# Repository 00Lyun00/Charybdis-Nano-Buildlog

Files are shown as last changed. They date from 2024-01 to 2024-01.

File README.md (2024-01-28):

# Charybdis Nano Buildlog
This is my rendition of the Charybdis Nano split keyboard made by [BastardKB.](https://github.com/bastardkb/charybdis)  
  
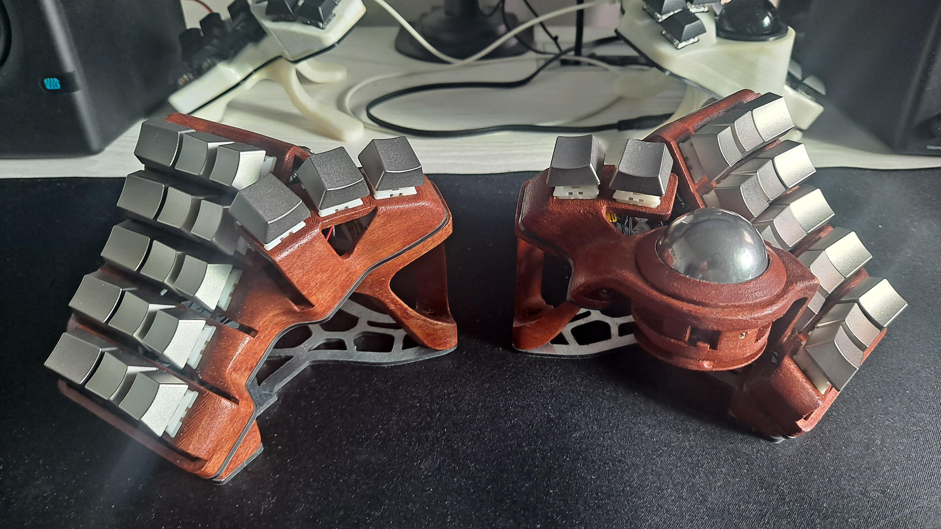
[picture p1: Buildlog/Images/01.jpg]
  
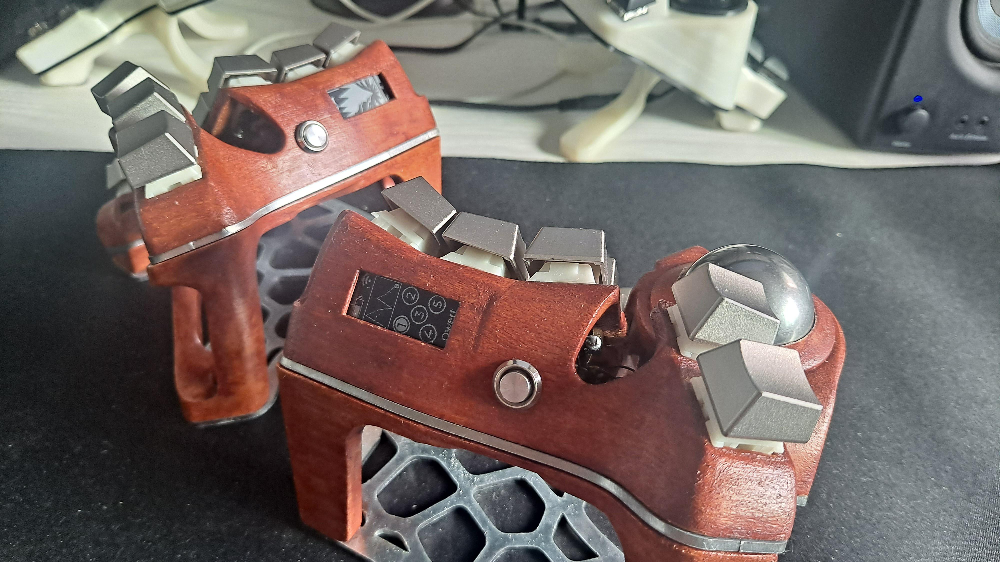
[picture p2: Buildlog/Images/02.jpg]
  
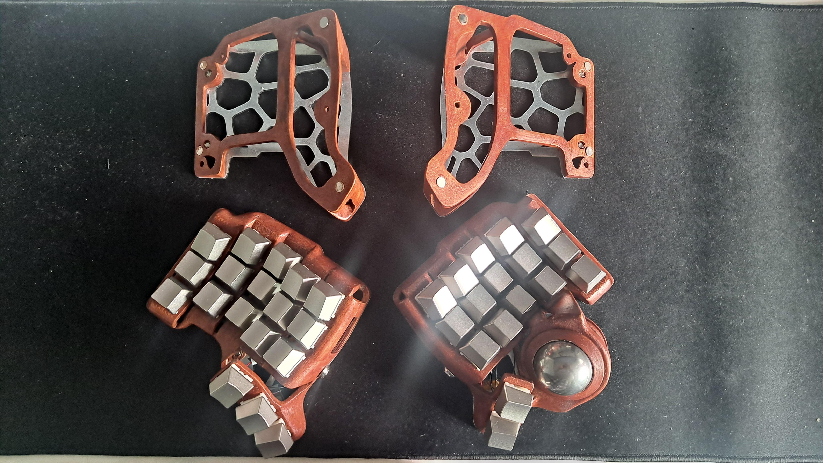
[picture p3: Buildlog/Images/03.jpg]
  
  
Intended to be a wireless-only build, I removed the TRRS jack on both cases, added walls to support a nice!view, and made holes to fit a metal on/off switch.  
I used the trackball cover mod to prevent the stainless steel ball from dropping out when I take it off the tent or MagSafe adapter.    
The alien tents have magnets imbedded, making it easier to attach and detach the keyboards.  
With 110mah batteries, I can use the fully charged keyboard for about 5 days before recharging.  
You can see a detailed buildlog in the Buildlog folder.  

## Materials
- Case: CooBean Wood PLA Filament, sanded, stained with generic mahogani wood stain and varnish
- Switches: Gazzew Boba U4
- Keycaps: Ogre Zinc Alloy OEM Keycaps (Korean Local Seller)
- Plates: Laserboost 2mm Galvanized Steel Plates
- Chair Attachment: Ulanzi R094 Magic Arm & Clamp + MagSafe Adapters
  
## Electronics    
- MCU: nice!nano 2.0
- Trackball Sensor: [ufan's original PMW3610 breakboard](https://github.com/ufan/pmw3610_breakout)
- Display: nice!view  
- ZMK Config: [My customized fork from EIGAtech's Config](https://github.com/00Lyun00/zmk-config-charybdis/tree/charybdis3.5)

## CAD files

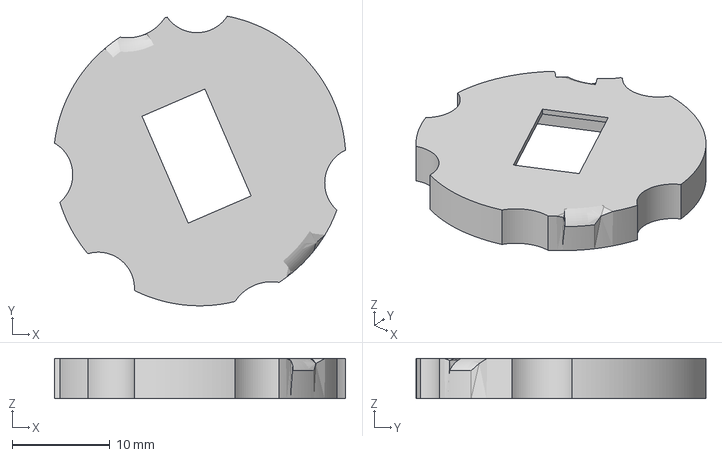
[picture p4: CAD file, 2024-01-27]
Buildlog/Files/PMW3610Adapter v2.3mf
29.7 x 29.6 x 4.10 mm

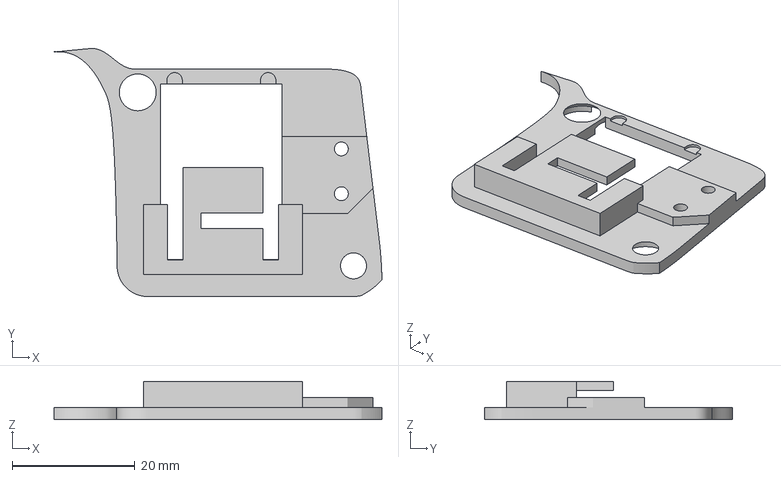
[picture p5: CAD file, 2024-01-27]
Buildlog/Files/MCUHolderRight.3mf
53.4 x 40.4 x 6.22 mm

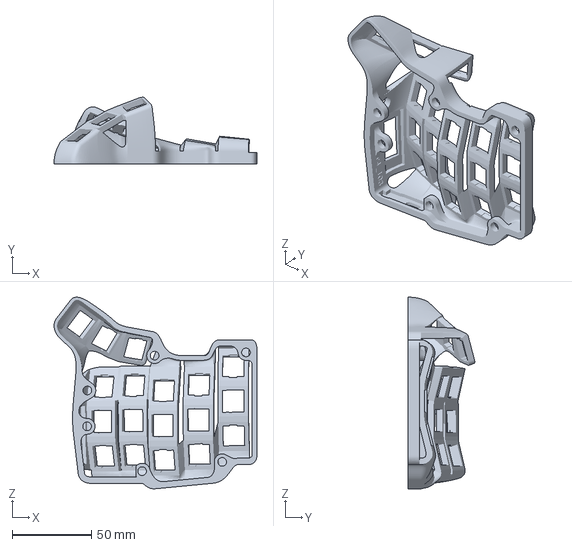
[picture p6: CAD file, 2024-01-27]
Buildlog/Files/WirelessSkeletyl.3mf
128.0 x 42.0 x 120.9 mm

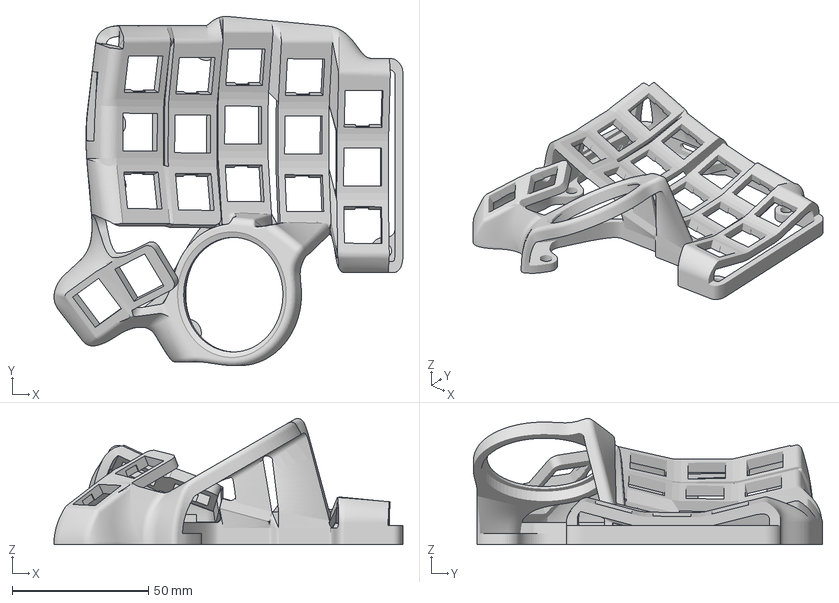
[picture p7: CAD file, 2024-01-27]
Buildlog/Files/WirelessCharybdisNano.3mf
128.0 x 128.1 x 46.2 mm

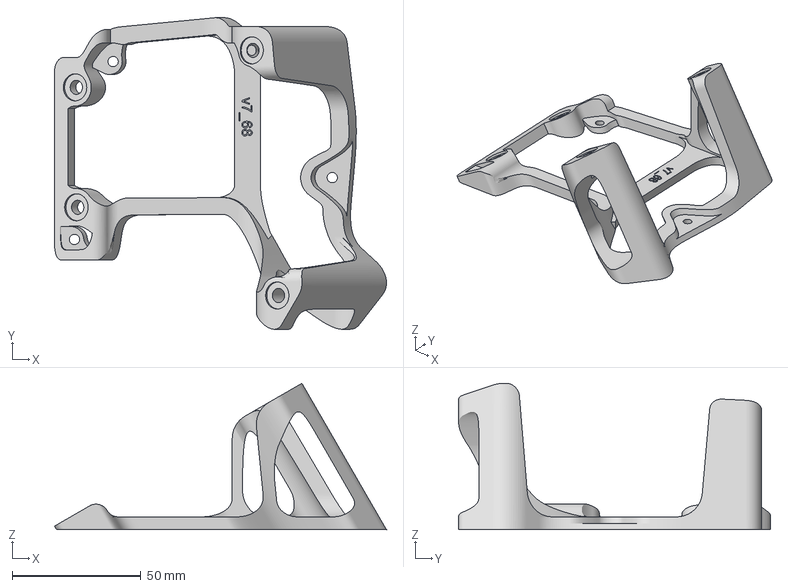
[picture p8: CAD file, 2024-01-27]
Buildlog/Files/AlienTentMagnet.3mf
128.8 x 120.9 x 56.8 mm

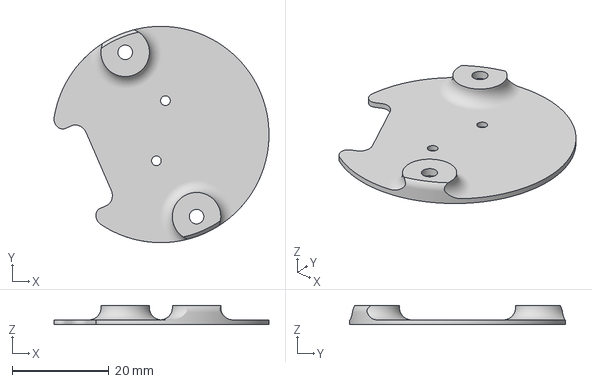
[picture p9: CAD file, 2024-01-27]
Buildlog/Files/PMW3610BottomPlate.3mf
44.4 x 44.7 x 4.00 mm

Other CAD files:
Buildlog/Files/MCUHolderLeft.3mf

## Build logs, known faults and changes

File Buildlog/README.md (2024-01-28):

This buildlog assumes the reader has prior experience in handwiring a keyboard and will skip that part. It is intended to help people with less experience in ZMK, as that was my case.  
   
## Planning
After being inspired to build this keyboard, the first goal I wanted to achieve was using capacitive touch to automatically switch to mouse layer.  
I knew this was possible as I saw username ufan mock up a test build with a stainless steel ball bearing in the ZMK Discord server, so I naturally decided to use one as well.  
With the constraint of having a stainless steel trackball, I thought wood and metal would create an intriguing vintage-furniture-like design.  
Although I learned that I didn't really need an auto-switch mouse layer and thus decided not to use capacitive touch later in the building process, I liked the design theme and decided to keep it.  
  
Regarding functionality, I wanted to make it wireless, add a button switch to save battery, add magnets to the original tents to attach/detach them conveniently, and install nice!view displays to know the pairing status and battery level.  
I knew the first three goals were achievable, but I've never seen someone using both a trackball and display on the same keyboard as pointing devices are currently experimental on ZMK.  
With these challenges in mind, I proceeded to the building process.  
  
I highly recommend watching [EIGAtech's wireless Charybdis video,](https://www.youtube.com/watch?v=Mks7QDxFreY&t) as it was incredibly helpful for me to visualize my build plan.

## Modeling
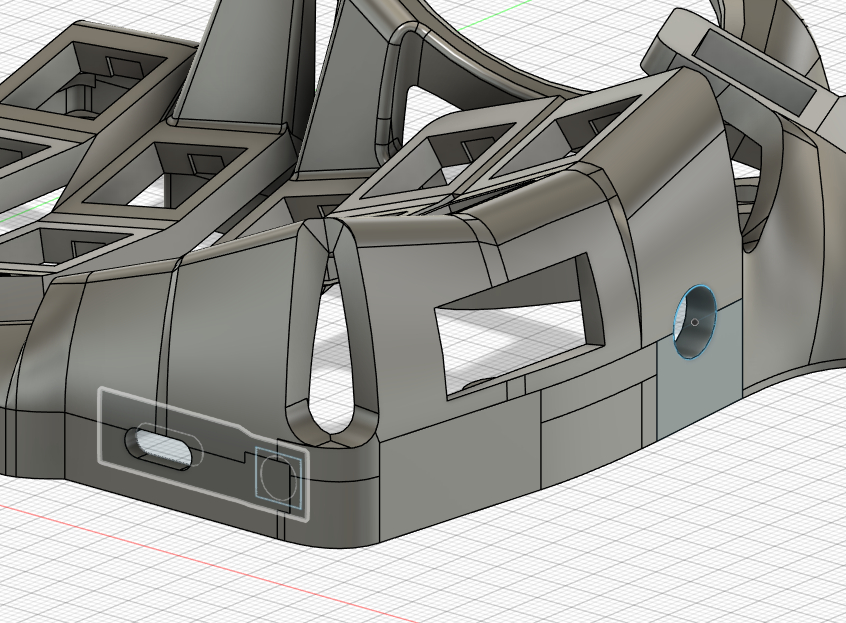
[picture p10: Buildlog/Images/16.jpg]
Three-quarter view of modified case
  
I have practically no knowledge in Fusion360, but as the changes I was about to make were minimal, it fortunately didn't deter the process too much.  
Firstly, I just simply added a hole on the side for the button switch and covered up the TRRS hole.  
I also changed the MCU holder for handwiring so that it didn't hold the TRRS conenector, grabbed on millmax hotswap sockets, and used a 3x6 button switch since that's what I had in stock.    
Everything except for the nice!view part was easy, as there was nothing to hold the nice!view to begin with.  
So I followed [BastardKB's keyboard design video](https://youtu.be/scoX8NZv4MI?si=uietOpE2jdQoaGku&t=1031) to make some walls on the side the exact way he did, and then I made a rectangular hole big enough to fit the nice!view flush.  
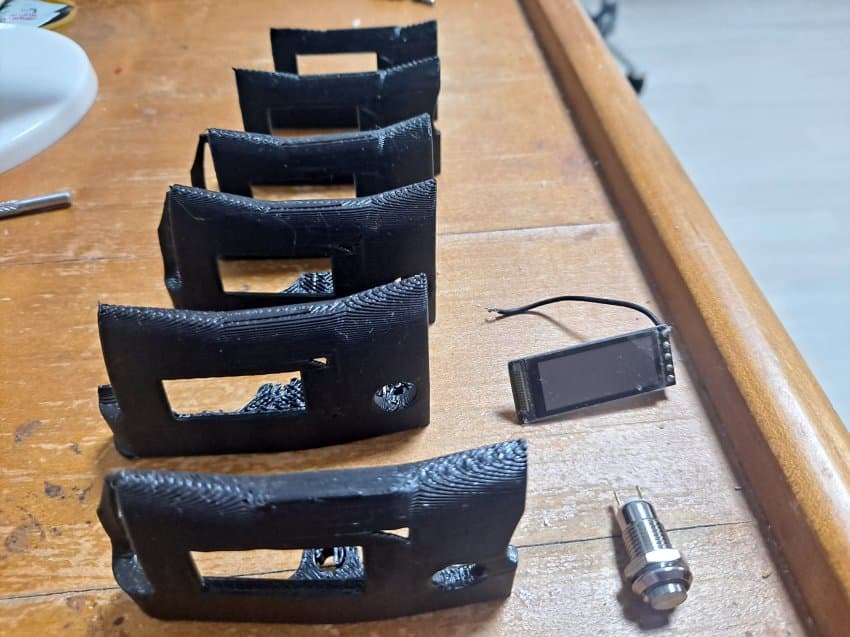
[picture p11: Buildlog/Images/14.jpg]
Multiple nice!view hole variations that show my inexpertise
  
If I was better in using Fusion360, I would have added a latch or any other mechanism to hold the nice!view in place.  
However, as I was limited by the fact that I don't know what I am doing, I simply stopped and decided to glue it in place.  
  
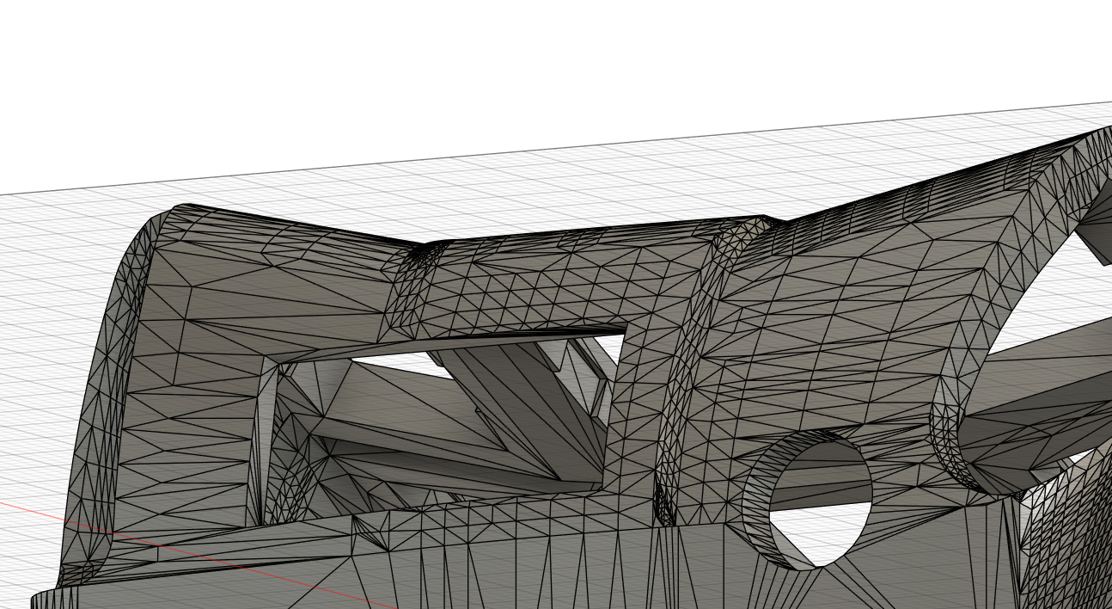
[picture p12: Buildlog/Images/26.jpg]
Flaw of Skeletyl file
  
  
The wall on the Skeletyl file is flawed because it sticks out a bit.  
I lacked the ability to fix this, so I just sanded it down after printing it until that bump disappeared.  
  
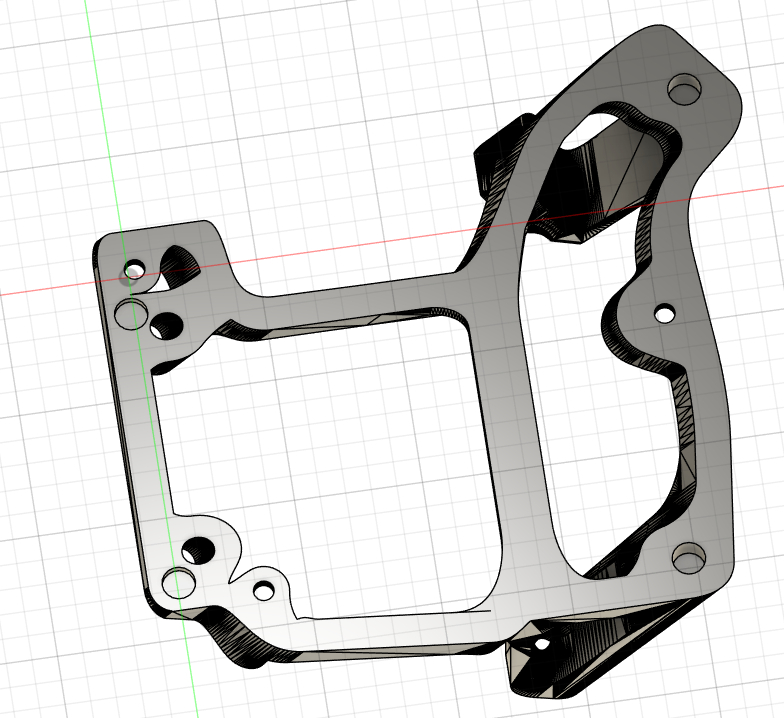
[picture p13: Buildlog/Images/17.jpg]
Alien tent modeling file
  
I also added four holes to the alien tent to hold 6cm magnets.  
The front legs were tall enough to fit two 3x6 magnets, and the back legs only managed to fit one 2x6 magnet each.  
I had to use the magnets this way in order to support the heavy keyboard in place without slipping.  
  
## Printing, Sanding, and Staining
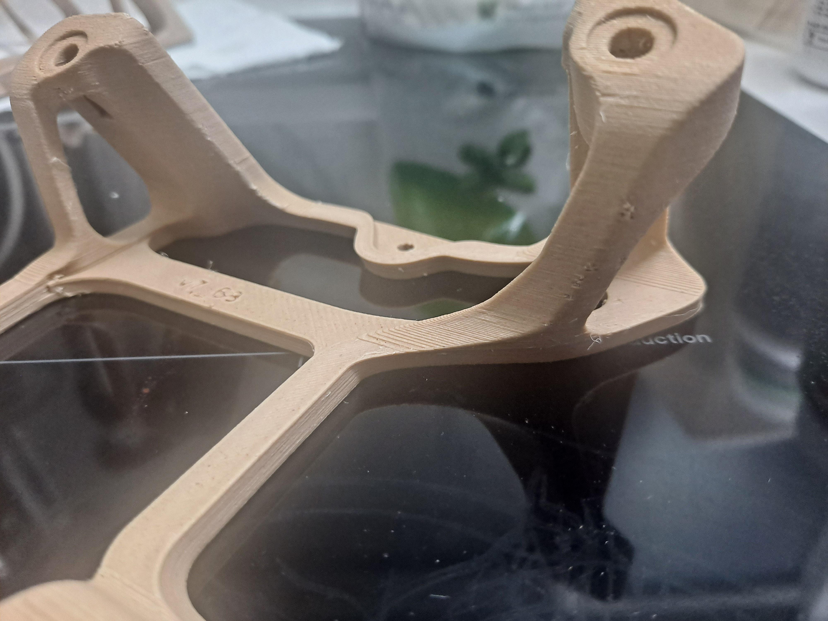
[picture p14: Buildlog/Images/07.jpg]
Unsanded tent
  
After the modeling process was finished, I 3D printed the cases and tents with wood PLA.  
I decided to use wood PLA was because I wanted the keyboard to feel like actual wood, and I saw some guides online that suggested sanding and staining.  
However, I later learned that just painting regular PLA like wood was way simpler, offered much more control, and achieved better results.  
If I were to rebuild this keyboard the same way, I think I would do that instead.  
  
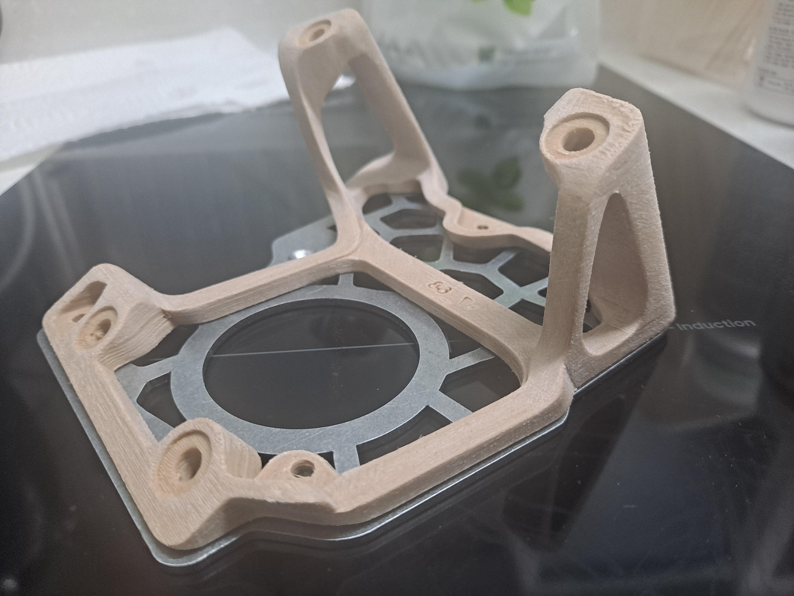
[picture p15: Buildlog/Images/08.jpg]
Sanded tent
  
I roughly sanded the printed 3D models with an 80 grit sandpaper to make it absorb the wood stain more easily.  
I could have used 160 or 200 grit sandpaper instead, but I expected the coarse 80 grit sandpaper to shorten the sanding process and produce a more unrefined, natural look opposed to the smooth, layered surface you get 3D printing.  
And I also tried to make the surface as smooth as possible without showing any staircase effects.  
  
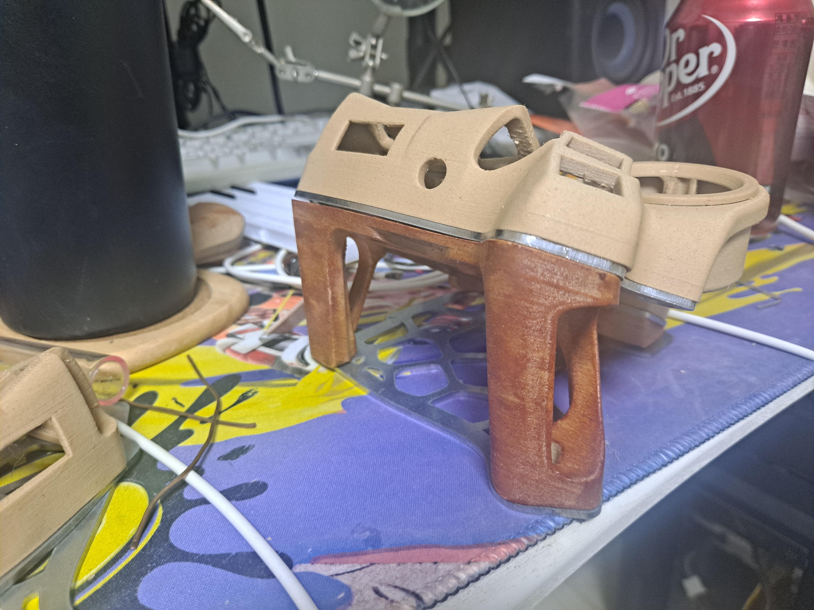
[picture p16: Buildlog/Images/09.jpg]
Stained case comparison
  
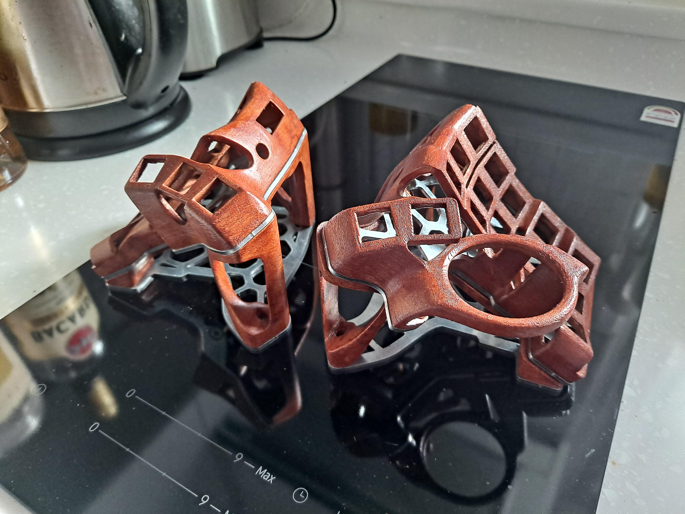
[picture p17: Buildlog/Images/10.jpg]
Finished case
  
Once the cases and tents were ready, I stained them with two to three coats of some generic wood stain and finished the surface with a matte varnish.  
The final product turned out a bit too bright and red than I intended, but it was acceptable so I moved on.  

## Wiring and Electronics
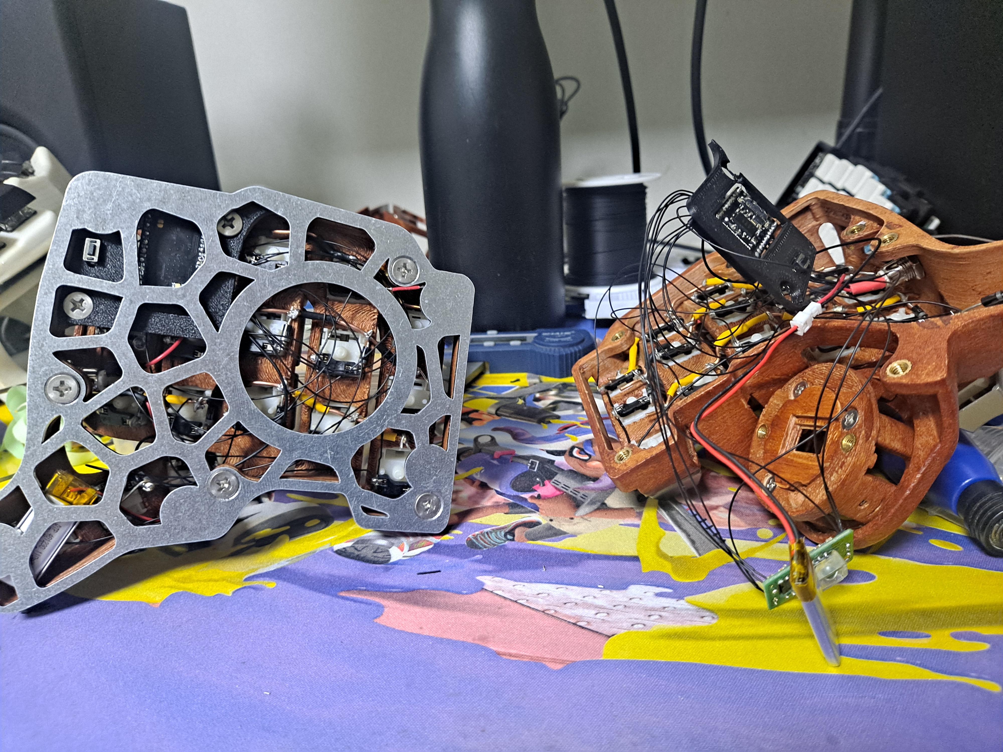
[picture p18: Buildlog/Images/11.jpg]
Messy handwiring
  
I handwired the keyboard because I happened to have everything I needed, and I wanted to save some money. I deeply regret this decision as the inner height of the Charybdis Nano is so low that the wire and hotswap sockets could touch the floor beneath the metal plate and potentially cause shorts. Due to this reason, I strongly recommend using flexible PCBs if you were to build a Charybdis Nano yourself.  
As I have little to no knowledge about electronics, all I am doing is guesswork based on pre-existing builds. This acted as a major obstacle for handwiring this keyboard as it meant I couldn't just install the firmware and had to figure out which wires were connected to which pin on the MCU.  
This is another reason why you should use flexible PCBs alongside [VOID's nice!nano holder](https://github.com/victorlucachi/Elite-C-holder), as everything is pre-positioned.  
So I dug up [EIGAtech's ZMK config](https://github.com/eigatech/zmk-config/tree/charybdis) to find out how everything had to be wired, and I found three important files.  

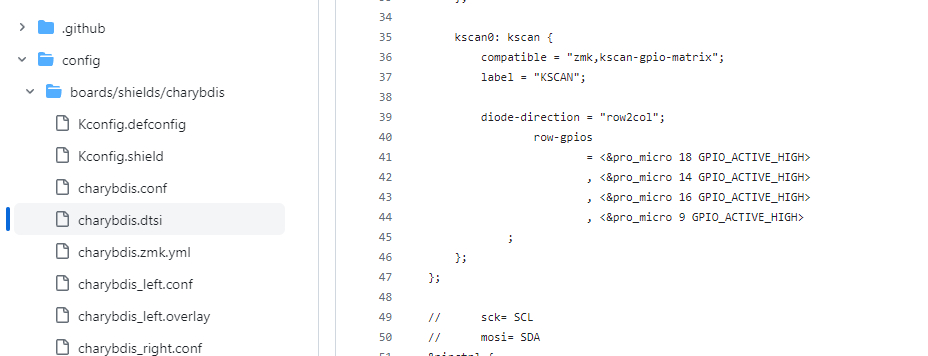
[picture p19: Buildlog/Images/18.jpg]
row2col and row pins
  
  
charybdis.dsti : Here, I found row2col and row-gpios. 
row2col means electricity flowed from rows to columns for keyboard scanning.  
It is very important to know this detail, as this indicates which direction we must wire the diodes so that we ensure electricity doesn't flow the opposite way.  
row-gpios showed which pins were assigned to each row, so I just had to wire them accordingly.  
And also, I don't have to stick to these pins and just change them in this file to whichever pin I like.  
This applies to all the pins with some exceptions, so you should keep that in mind.  
  
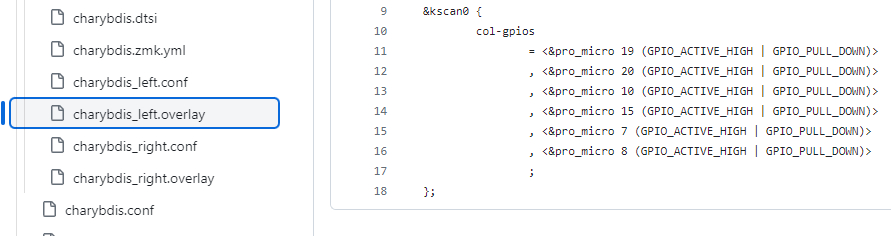
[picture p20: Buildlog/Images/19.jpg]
column pins
  
  
charybdis_left.overlay : Here I found col-gpios. This told me where to wire the columns.  
One small issue I had was that this config was written for the 3x6 Charybdis Mini, but I was making a 3x5 Charybdis Nano.  
So there was one excess column pin that wasn't used on my keyboard, and I didn't know which one it was.  
To solve this problem, I just wired column 2 and tested which column it was on the keyboard to find out whether column 1 or 6 was unused.  
It was column 1, so I just didn't wire anything to it.  
  
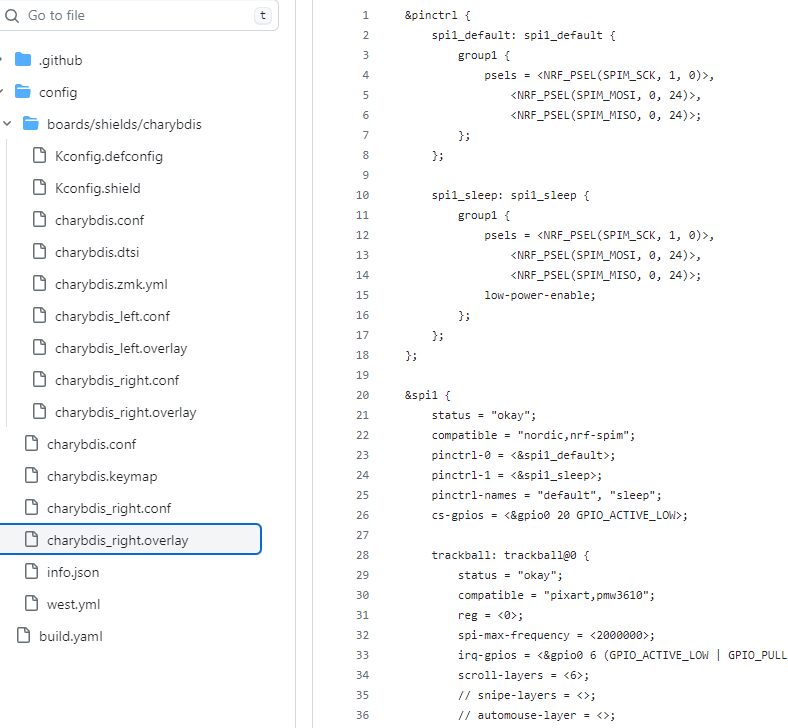
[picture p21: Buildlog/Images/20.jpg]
trackball pins
  
  
charybdis_right.overlay : Here I found &pinctrl and &spi1. This showed me which pins were assigned for the trackball sensor.  

Now I just had to learn how to add a nice!view to the keyboard, so I searched online to find ZMK configs that had nice!view added to their keyboards.  
  
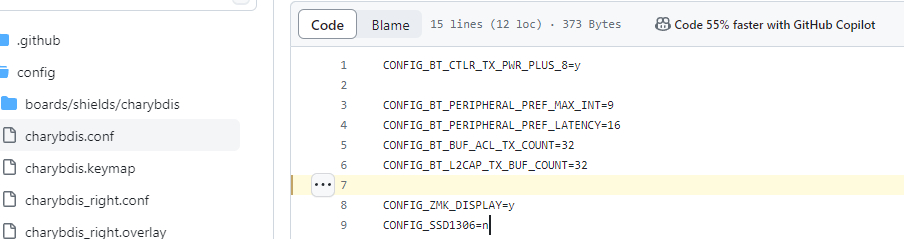
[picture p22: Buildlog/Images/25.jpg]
niceview charybdis.conf
  
  
In charybdis.conf, you have to add CONFIG_ZMK_DISPLAY=y and CONFIG_SSD1306=n as seen in the screenshot above.  
  
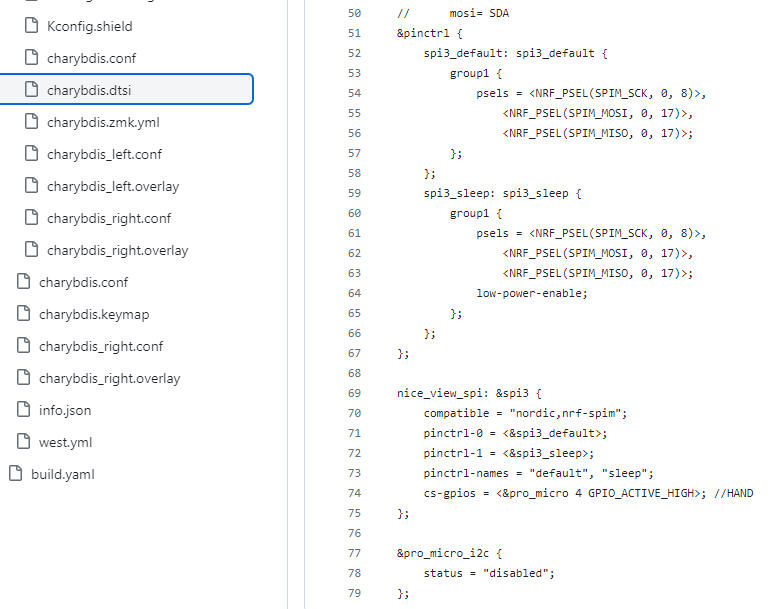
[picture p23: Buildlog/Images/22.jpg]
niceview charybdis.dtsi
  
  
In charybdis.dtsi, you have to add the entire &pinctrl and nice_view_spi sections as seen in the screenshot above.  
  
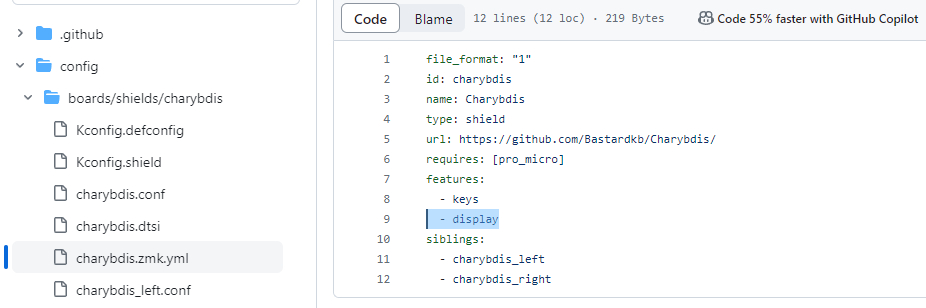
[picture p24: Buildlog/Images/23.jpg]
niceview charybdis.zmk.yml
  
  
In charybdis.zmk.yml, you have to add - display under the features section.  
  
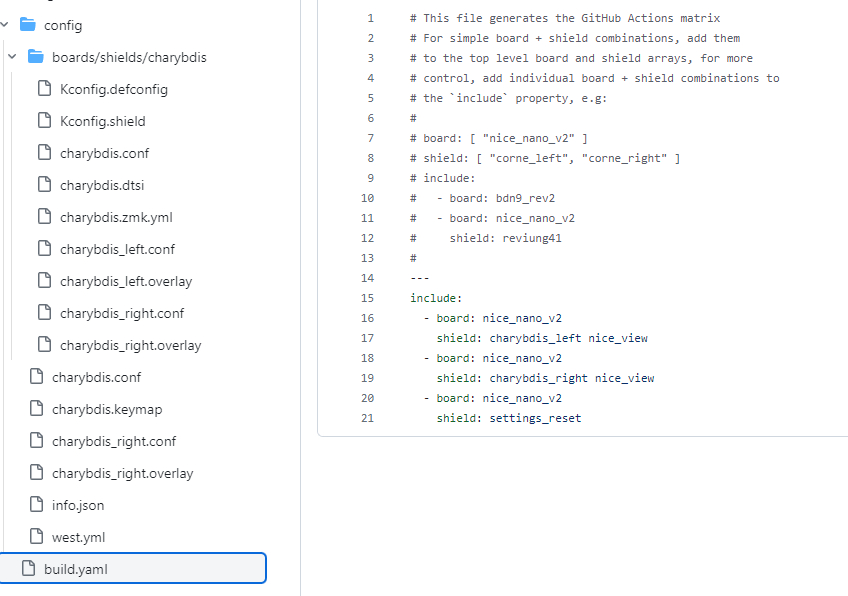
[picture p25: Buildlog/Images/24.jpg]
niceview build.yami
  

And most importantly, in build.yami, you have to add nice_view behind both shield: charybdis_left and shield: charybdis_right as seen above.  
I am not sure if you have to do all of these changes, but they are what I did to make the nice!view work on my keyboard.    
I hope it is clear that you can change all of the file names from charybdis to whatever keyboard you want to add the nice!view to.  
  
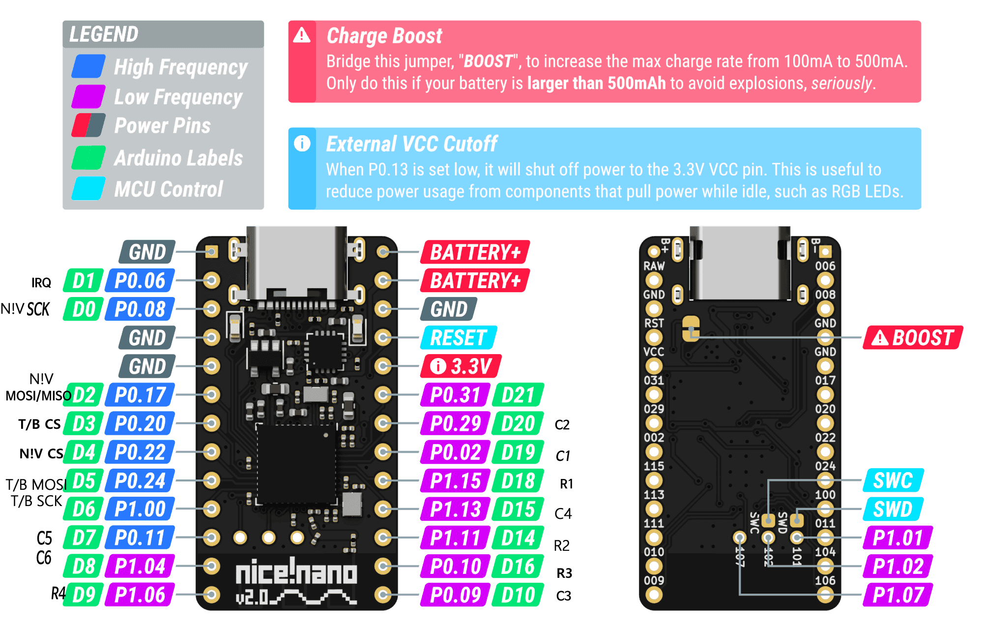
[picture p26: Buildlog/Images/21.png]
My pinout
  
With all the info I needed to handwire the keyboard, I came up with this pinout.  
Please note that column 1 isn't used for my keyboard, and it represents the sixth and outermost column you press with your pinky.  
The trackball/nice!view SCK/MOSI/CS pins each can be interchanged with their corresponding positions.  
Although I ended up with this seemengly random placement, I would rather recommend organizing it to be more easily comprehensible if you were to build this keyboard yourself.  
But keep in mind that it is preferred to use high-freuquency pins for the nice!view and trackball sensor.  

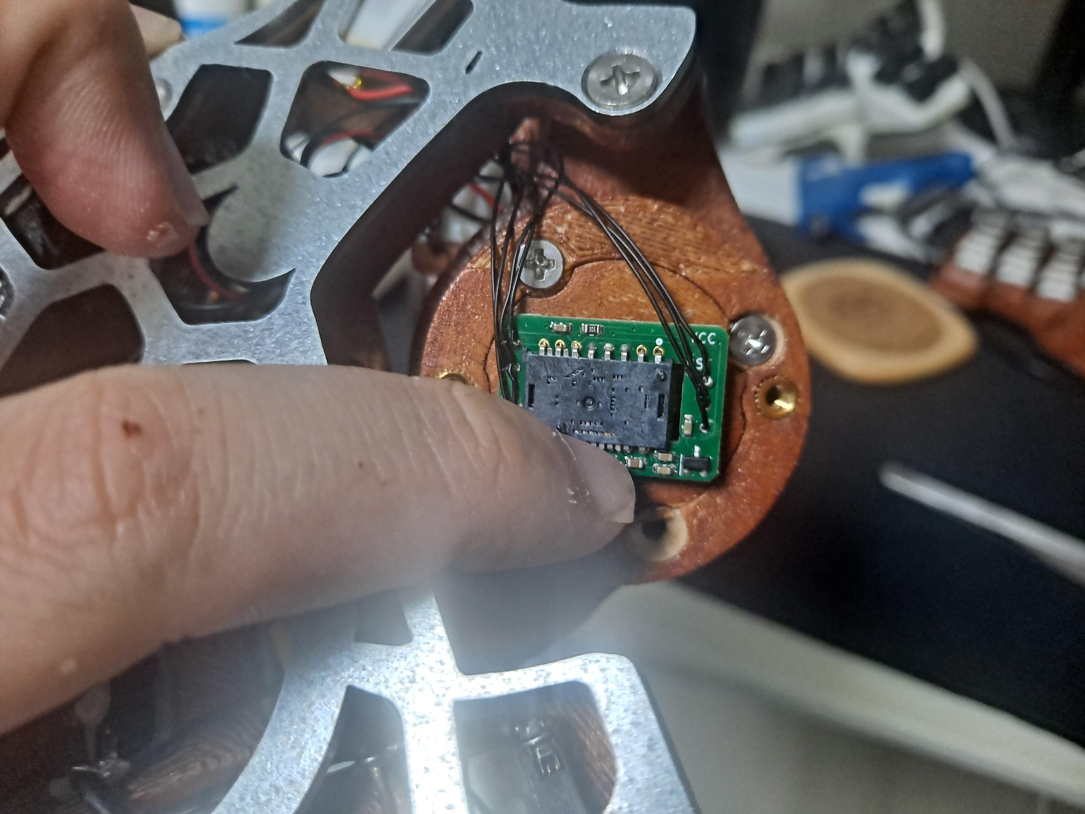
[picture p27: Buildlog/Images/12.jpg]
Positioning the trackball sensor
  
I used [ufan's original pmw-3610 breakboard](https://github.com/ufan/pmw3610_breakout) opposed to the [Charybdis pmw-3610 breakboard](https://github.com/Bastardkb/charybdis-pmw3610-breakout) because it was smaller, and since I am forced to buy 5 of these at least when ordered from JLCPCB, I planned to use the leftover ones for different keyboard projects.  
However, this meant the pmw-3610 doesn't have a way to be positioned correctly, so I had to change VOID's trackball sensor adapter to hold the pmw-3610 in place.  
I have failed in fine-tuning the position, and I worked around this problem by adjusting how tightly the bottom screws are turned.   
The trackball position must be in the exact configuration shown in the photo to work with my settings, and I strongly recommend using the Charybdis breakboard as it is very finicky to work with and hard to callibrate.  

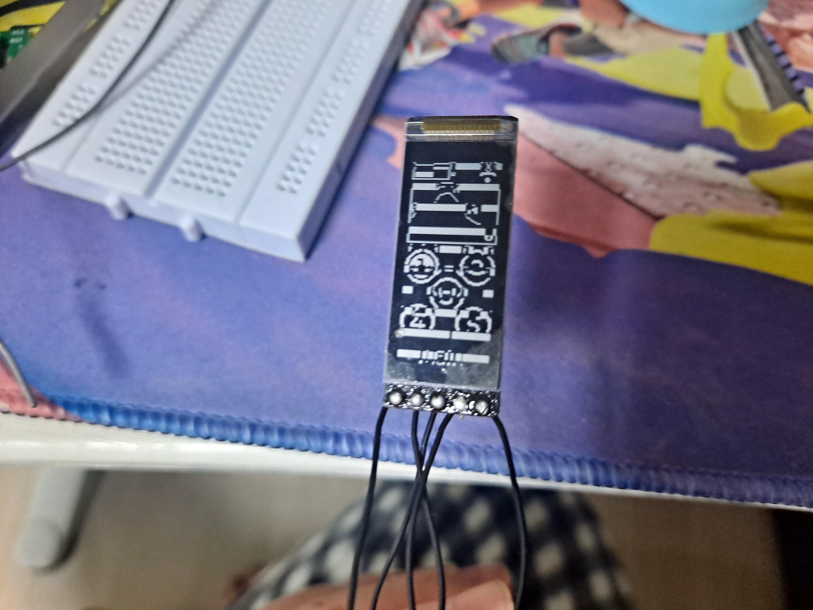
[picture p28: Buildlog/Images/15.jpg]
nice!view malfunctioning
  

As far as I know, nobody wired a nice!view to a keyboard with a pointing device on ZMK, so I didn't know how their SPIs would interact, let alone what an SPI even is. 
I first thought they could share the same spi device and wired them to the exact same pins, and the nice!view started malfunctioning as shown in the photo.  
This is a very stupid thing to do in hindsight, but my lack of knowledge prevented me from realizing what an idiot I was.  
Whatever signals sent by the trackball interferred with the nice!view, and now I know they must use different pins.  
I set the trackball to use spi1, the nice!view to use spi3, wired the trackball and nice!view to different pins, and everything worked flawlessly.  
I then tested to see if they just had to use different pins and was able to share the same spi device, but although the nice!view screen showed up normally, the trackball didn't work.  
Maybe there might be an error on my side, but with this, I came to believe that the trackball sensor and nice!view must use both different pins and spi devices.  

## Final Stretch
With the keyboard now functioning properly, I just had to get keyswitches and keycaps to finish the build.  
I got Gazzew Boba U4 keyswitches as I prefer having no noise, and I got a set of Ogre zinc alloy keycaps to further push the metal-wood aesthetics.  
They feel cold to touch for the first couple minutes, but they'll warm up eventually. Sometimes they make a metallic clank sound when I type, which I think is cool.  
The Ogre keycaps have an OEM profile, and they are sold in Korea for roughly $48 for 72 caps, making them far more affordable than aluminum or stainless steel keycaps.  
However, as zinc alloy keycaps are notoriously subseptible to discoloration, I might have to replace them after a couple months or years later.  
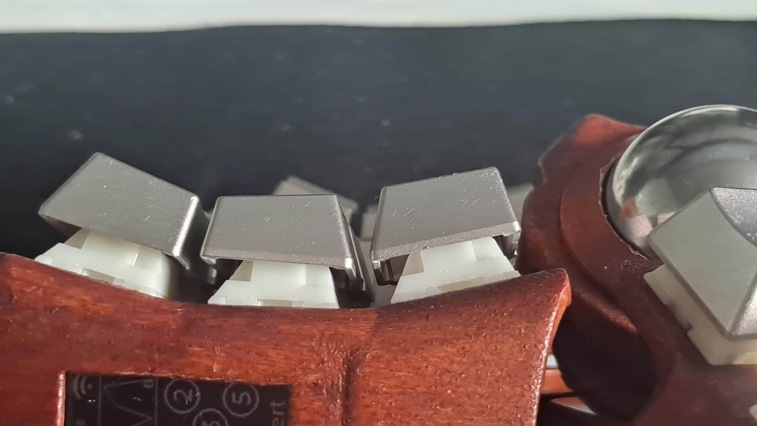
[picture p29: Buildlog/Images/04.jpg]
Pseudo-keywell
  
I've installed the R4 keycaps upside down on row one and R2 and R3 keycaps on rows two and three, thus creating a pseudo-keywell structure.  
It would have been better to use other keycaps, but as these were the only metal keycaps I was willing to afford, I had to make use of what I could.  
The pseudo-keywell had a surprisingly satisfying curvature, although the bottom row felt a bit flat.  
To me, it is not inferior to uniform DSA keycaps, albeit having strengths and shortcomings in different areas.  
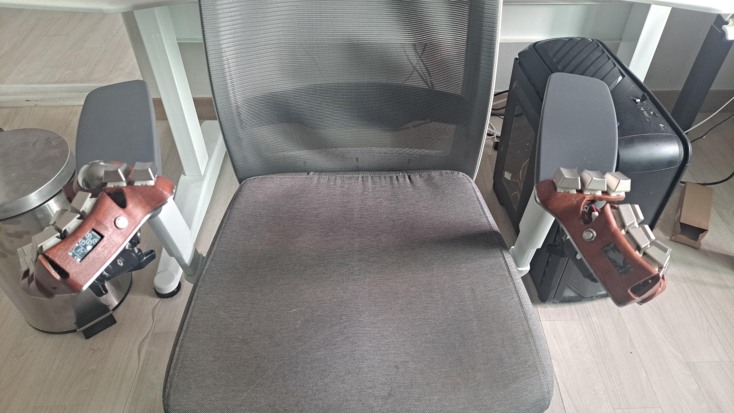
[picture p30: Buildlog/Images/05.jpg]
Captain's chair
  
I mainly use the keyboard clamped to my chair with MagSafe adapters and 141cm magic arms.  
It is very convenient to type with, and the 110mah battery lasts about 5 days.  
When I don't use the keyboard, I detach both halves and place them on the magnetic alien tents as display.    

## Limitations
Now with the keyboard finished, there are some huge flaws that must be fixed.  
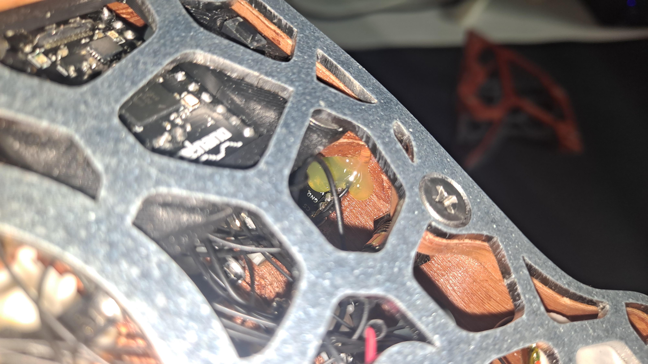
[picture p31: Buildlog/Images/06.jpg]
nice!view hotglued in place
    
1. The nice!view must have a non-destructive way to install. I just hotglued mine and they work fine to me, but this is not a reliable way to manufacture a keyboard, and I will have a huge problem replacing them when they eventually break down.  
2. The right half resets sometimes when I detach it from the chair. I believe this is happening due to a short, but it is practically impossible to address as I did a messy job handwiring the keyboard.  
3. My ZMK config is outdated. Whenever I turn off the keyboards, the peripheral left half loses connection to the right half and fails pairing. This was fixed by adding CONFIG_ZMK_BLE_EXPERIMENTAL_CONN=y in charybdis.conf, but it in turn drains the left half's battery extremely fast, so it also only lasts about 5 days and not the expected one month. I can actually fix this easily by using the most recent ZMK pointer branch, so it isn't as critical as the other flaws. 
4. I am using a 3x6 Charybdis Mini firmware instead of a 3x5 Charybdis Nano firmware. Although it is functioning perfectly, I am basically using a 3x6 keymap with all of the outer column keys left blank. It is a bit of a hassle to work with, and it would be much more nice to just set it as a 3x5 keyboard in the first place.  
5. The trackball sensor isn't perfectly aligned to the trackball. As I fastened ufan's breakboard by modifying VOID's pmw-3610 adapter, it is less precisely positioned than the Charybdis pmw-3610 breakboard that is always guaranteed to be in the same height and orientation. Due to this flaw, the track ball sometimes doesn't work, and I have to press on the bottom of the cover and tap it a bit to make it work properly. This can be fixed by modifying VOID's pmw-3610 adapter and the trackball sensor bottom cover, but although I am currently working on it right now, it will take a huge amount of trial and error.  

Because of the reasons listed, I do not recommend building this keyboard the way I did.  
Instead, I'd recommend using flexible PCBs, the Charybdis pmw-3610 breakboard, and [VOID's nice!nano holder](https://github.com/victorlucachi/Elite-C-holder). And I don't think you should use nice!views for the current time.  
And I would also recommend buying [BastardKB's Charybdis kit](https://bastardkb.com/charybdis) as it's a very nice way to get most of the materials.  
Maybe I will update the 3D files in the future, but I am mentally satisfied with what I have accomplished, and it will take a lot of motivation and learning until I muster up the will to fix them.

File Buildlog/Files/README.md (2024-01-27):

These are the 3D modeling files I have modified for this project.  
The original keyboard case designs are from [BastardKB's Charybdis Github repository,](https://github.com/Bastardkb/Charybdis) and the original pmw-3610 adapter is from [VOID's pmw-3610 breakout Github repository.](https://github.com/victorlucachi/charybdis-pmw3610-breakout)  
I do not own any copyright of these files, and no copyright infridgement is intended.  
The bottom case plates, bottom alien tent plate, top trackball adapter, and bottom sensor adaptor are not included, which can be found in BastardKB's Github repository.  
I do not recommend using these files for your own build as they are inherently flawed and rudimentary.  
I hope these files inspire whoever is interested in making better revisions.

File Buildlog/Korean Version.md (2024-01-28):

해당 제작기는 독자가 핸드와이어링으로 키보드를 만든 적이 있음을 상정하고 해당 부분은 건너뛰었습니다. 전체 내용은 작성자가 ZMK로 키보드를 빌드한 경험이 없어서 헤멘 경험을 바탕으로 같은 조건에 있는 사람들을 돕기 위해 작성되었습니다.  
   
## 계획하기
이 키보드를 만들기로 결정하면서 가장 우선적으로 달성하고자 한 목표는 정전식 터치 센서를 사용해서 마우스 레이어로 자동으로 전환하게 만드는 것이었습니다.  
ZMK 디스코드에서 ufan 이라는 사용자가 스테인레스 볼 베어링을 써서 구현한 것을 본 적이 있기 때문에 이게 가능하다는 걸 알았고, 그래서 저도 자연스럽게 스테인레스 베어링을 쓰기로 결정했습니다.  
일단 쇠공을 트랙볼로 쓰는 게 결정되었으니, 저는 목재와 금속을 같이 쓰면 뭔가 빈티지 목공예품 느낌으로 인상적인 디자인이 나올 거 같았어요.   
그래서 비록 제작 도중에 정전식 터치가 굳이 필요가 없다는 걸 배워서 해당 기능은 포기했으나, 디자인 방향 자체는 마음에 들어서 계속 진행하기로 했습니다.  
  
기능 면에 있어서는 저는 키보드가 무선으로 동작하고, 버튼 스위치로 켜고 끌 수 있게 만들어서 배터리를 절약하고, 텐트에 자석을 달아서 탈부착하기 쉽게 만들며, nice!view 디스플레이를 달아서 스플릿 연결 상태와 배터리 잔량을 쉽게 알 수 있도록 만들고자 했습니다.  
처음 세 목표는 달성이 가능하다는 걸 알았지만 제작 시점에서는 트랙볼과 디스플레이를 동시에 사용하는 사람을 본 적이 없고 ZMK에서 마우스 기능은 제한적이라서 불확실했습니다.  
앞으로 키보드를 만들기 위해 뭘 해야 할 지 확실해지자 저는 제작 단계로 넘어갔습니다.  
  
제작할 때 유튜브 채널 [EIGAtech의 무선 카리브디스 키보드 제작 영상이](https://www.youtube.com/watch?v=Mks7QDxFreY&t) 크게 도움이 되었고, 관심이 있으신 분께서는 이를 시청하실 것을 권고합니다.  

## 모델링
정측면 각도에서 본 수정한 모델링  
저는 퓨전360 기능을 거의 모르지만 어차피 제가 수정하는 거는 매우 간단한 것들에 불과해서 제작 과정이 크게 지체되지 않았습니다.  
처음에는 케이스 옆면에 버튼 스위치가 들어갈 구멍을 하나 뚫고, 앞면에 TRRS 커넥터가 꽂히는 구멍을 메웠습니다.  
핸드와이어링할 때 쓰는 MCU 홀더도 모양을 좀 수정해서 TRRS 커넥터 지탱하는 부분을 없애고, 밀맥스 소켓을 꽂을 수 있게 만들고, 3x6 리셋 버튼을 쓰게 만들었습니다.  
여기까지는 다 쉬웠는데, 이제 nice!view 를 다는 곳을 만들려 하다 보니 애초에 이걸 붙잡을 수 있는 벽 자체가 없었습니다.  
그래서 원 제작자인 [BastardKB가 키보드 디자인 과정을 보여주는 유튜브 영상을](https://youtu.be/scoX8NZv4MI?si=uietOpE2jdQoaGku&t=1031) 참고해서 똑같은 방법으로 측면에 벽을 만들었고, 그 다음에 사각형 모양 구멍을 뚫어서 nice!view가 딱 맞게 들어가도록 만들었어요.  
실력부족을 보여주는 nice!view 지지대 하자품들  
만약 제가 퓨전을 제대로 쓸 줄 알았다면 무슨 걸쇠나 기타 지지 부품을 만들어서 nice!view가 제자리에 고정되게 만들었을 건데  
저는 제가 뭘 하는지도 잘 모르는 상태였기 때문에 그냥 여기서 멈추고 글루건 써서 고정하기로 했습니다.    
  
스켈레틸 결함  
  
스켈레틸 케이스는 벽 부분이 위쪽으로 돌출되는 결함을 지녔습니다.  
제 능력으로는 이걸 고칠 수가 없어서 그냥 3D프린팅을 한 뒤 사포로 갈아서 없앴습니다.  
  
텐트 모델링  
키보드 텐트에도 지름이 6cm인 자석을 달 수 있게 구멍을 네 개 뚫었습니다.  
앞쪽은 3x6 자석을 두 개씩 넣을 수 있을 정도로 높았고, 뒤쪽은 높이가 워낙 낮아서 2x6 자석을 하나씩만 겨우 넣을 수 있었습니다.  
자석을 이 정도로는 써야 키보드가 미끄러지지 않고 제자리에 고정되었습니다.  
  
## 3D 프린팅, 사포질, 우드 스테이닝
사포질이 안된 텐트  
모델링 단계가 끝난 뒤 저는 우드 PLA 필라멘트를 써서 케이스와 텐트를 프린팅했습니다.  
우드 필라멘트를 쓴 이유는 키보드를 최대한 진짜 목공예품처럼 느껴지게 하고 싶어서 그랬고, 온라인에서 찾아보니 우드 필라멘트를 사포질하고 스테이닝 하는 게 좋은 결과를 가져온다는 글을 찾았기 때문입니다.  
허나 제작 도중에 그냥 일반 필라멘트로 뽑은 뒤 나무 느낌으로 도색하는 거가 훨씬 절차가 쉽고, 더 세세적으로 조절하기 편하며, 결과물도 더 좋다는 걸 배웠습니다.  
만약 제가 이 키보드를 다시 만든다면 그때는 그냥 일반 필라멘트로 도색을 할 것 같습니다.  
  
사포질이 끝난 텐트  
저는 80방 사포를 써서 키보드 표면을 사포질해서 우드 스테인을 더 잘 흡수할 수 있게 만들었습니다.  
이때 160방이나 200방을 쓸 수도 있는데, 저는 80방 쓰는 게 전체 사포질 과정을 단축시키고, 원래의 미끈하고 층층이 쌓인 3D프린팅 표면보다 더 거칠고 자연스러운 나무 느낌을 내는 것을 기대했습니다.  
또한 사포질하면서 계단현상이 안 보이게 표면을 최대한 미끈하게 만들었습니다.  
  
케이스 스테이닝 전후 비교  
완성된 케이스  
키보드 케이스와 텐트를 전부 사포질한 뒤, 대충 싸구려 우드 스테인으로 두 세 번 정도 코팅해서 칠하고 무광 바니쉬를 마무리로 발라줬습니다.  
최종 결과물은 제가 원했던 것보다 너무 밝은 붉은색이 되었지만 그럭저럭 받아들일 만해서 다음 단계로 넘어갔습니다.  

## 와이어링과 펌웨어
조잡한 핸드와이어링  
저는 이 키보드를 핸드와이어링으로 만들었는데, 그 이유는 마침 집에 재료가 다 있었고 돈을 아끼고 싶었기 때문입니다. 이 결정은 나중에 가서 깊이 후회하게 되었는데, 왜냐하면 카리브디스 나노 키보드는 높이가 엄청 낮아서 내부의 전선이랑 핫스왑 소켓이 철판 밑에 있는 바닥에 닿아서 자칫하면 쇼트를 낼 수 있기 때문입니다. 이런 이유로 만약 카리브디스 나노를 제작할 거면 플렉서블 PCB를 쓸 것을 강력하게 권고합니다.  
저는 ZMK 펌웨어를 코딩하는 법을 거의 모르기 때문에 이미 존재하는 펌웨어를 막 뒤져가며 대충 어떻게 돌아가는 거구나 하고 추측을 하는 게 전부였습니다. 키보드를 핸드와이어링하는 게 그래서 엄청 큰 문제가 되었는데, 얘는 제가 MCU에서 어떤 핀에다 전선을 연결하는지 모르니까 PCB를 납땜하듯 그냥 대충 만들고선 펌웨어 설치한다고 해서 저절로 작동하는 게 아니기 때문이에요.  
그래서 만약 이 키보드를 만들 거라면 플렉서블 PCB와 함께 이미 펌웨어에 맞춰서 모든 핀이 다 제대로 설정이 된 [VOID가 만든 nice!nano 홀더를](https://github.com/victorlucachi/Elite-C-holder) 쓰는 게 좋습니다.  
저는 어떤 핀에 와이어링을 해야 하는지 알아내기 위해 [EIGAtech 의 ZMK 펌웨어에](https://github.com/eigatech/zmk-config/tree/charybdis) 들어가서 파일을 전부 뒤져봤고, 그 결과 중요 파일 세 개를 찾았습니다.  

row2col과 row-gpios  
  
charybdis.dsti : 이 파일 내에서는 row2col 와 row-gpios 을 찾아 볼 수 있습니다. 
row2col 은 무슨 뜻이냐면 키보드 매트릭스를 스캔할 때 전류가 행에서 출발해서 열로 나간다는 뜻입니다.  
이는 매우 중요한 디테일인데, 전류가 어떤 방향으로 흐르는지 알아야 다이오드를 올바른 방향으로 납땜해서 전류가 반대 방향으로 안 흐르고 정상적으로 작동하게 만들 수 있습니다.  
row-gpios 는 어떤 행이 어떤 핀에 연결되는지 보여줘서 저거에 맞게 와이어링을 하면 됩니다.  
아니면 굳이 똑같은 핀에 고집할 필요 없이 핀 번호를 수정해서 딴 핀에 와이어링하게 만들 수도 있어요.  
이건 일부 예외를 제외하고 모든 핀에 적용되는 사항이니 알아두는 것이 좋습니다.  
  
col-gpios  
  
charybdis_left.overlay : 여기서는 col-gpios 를 찾아냈는데, 얘는 어떤 열을 와이어링해야 하는지 보여줘요.  
이때 한 가지 문제가 있었는데, 이 펌웨어는 3x6 배열인 카리브디스 미니 용으로 제작되었는데 문제는 제가 만드는 건 3x5 배열인 카리브디스 나노라는 겁니다.  
즉 이 키보드에는 제가 사용하지 않는 열이 하나 존재하나, 그게 정확히 몇번 열인지를 펌웨어만 보고서는 알 방법이 없었습니다.  
이를 해결하기 위해 저는 일단 2번열을 핀에 연결한 다음에 눌러서 얘의 상대적인 위치를 파악했고, 그래서 키보드에 1번열이 없는 건지 6번열이 없는 건지 확인했습니다.  
1번열이 없는 거였고, 그래서 이 핀은 아무것도 연결하지 않았어요.  
  
트랙볼 핀  
  
charybdis_right.overlay : 여기서는 &pinctrl 하고 &spi1 을 찾았습니다. 얘네는 트랙볼 센서를 어떻게 연결해야 하는지 알려줬어요.  

이제 키보드에 nice!view를 달기만 하면 되어서 온라인에 딴 사람들 ZMK 펌웨어를 찾아봐서 이걸 어떻게 추가하는 건지 알아봤습니다.  
  
niceview charybdis.conf  
  
Charybdis.conf 파일에는 위에 보이는 대로 CONFIG_ZMK_DISPLAY=y, 그리고 CONFIG_SSD1306=n 를 추가해야 합니다.  
  
niceview charybdis.dtsi  
  
charybdis.dtsi 파일에는 &pinctrl 이랑 nice_view_spi 섹션 전체를 위에 보이는 대로 추가해야 합니다.  
  
niceview charybdis.zmk.yml  
  
charybdis.zmk.yml 에는 features 라고 쓰인 거 밑에 - display 라고 추가해야 합니다.  
  
niceview build.yamy  

그리고 이게 가장 중요한 부분인데, build.yami 파일에는 nice_view 라는 문구를 shield: charybdis_left 하고 shield: charybdis_right 둘 다 뒤쪽에다 붙여써야 합니다.  
요 설정들을 전부 다 해야 nice!view가 작동하는 건지 아닌지는 모르겠는데, 적어도 저는 저걸 다 한 상태에서 nice!view 가 정상 작동했습니다.  
여기서 키보드 이름은 꼭 charybdis 일 필요가 없고 자기 키보드 이름을 쓰기만 하면 됩니다.  
  
핀아웃  
이제 핸드와이어링을 하기 위한 정보를 전부 취합했으니, 저는 위에 보이는 대로 핀아웃을 구성했습니다.  
제 키보드는 1번열을 안 쓰고, 여기서 1번열은 카리브디스 미니에서 새끼손가락으로 누르는 키보드 최외곽열이라는 점을 명심하세요.  
트랙볼이랑 nice!view 가 쓰는 SCK/MOSI/CS 핀들은 서로 위치를 바꿀 수 있습니다.  
비록 제 핀아웃은 엄청 조잡하게 완성되었지만, 만약 이걸 직접 만들 거라면 좀 정리해서 더 깔끔하게 만드는 것을 권고합니다.  
다만 nice!view 랑 트랙볼 센서는 원할히 작동하기 위해 high-freuquency 핀을 써서 연결하는 게 좋습니다.  

트랙볼 센서 위치 조정  
트랙볼 센서로 저는 [카리브디스용 pmw-3610 보드](https://github.com/Bastardkb/charybdis-pmw3610-breakout) 대신에 [ufan의 원조 pmw-3610 보드를](https://github.com/ufan/pmw3610_breakout) 썼는데, 그 이유는 이게 더 작고, 어차피 JLCPCB에서 최소 주문량인 5개를 주문해야 하니까 나머지 보드를 써서 다른 키보드를 만들고자 했기 때문입니다.  
하지만 이러면 pmw-3610 센서를 정확한 위치에 고정할 방법이 사라지기 때문에 저는 VOID가 만든 트랙볼 센서 어댑터 파일을 개조해서 pmw-3610 센서를 제자리에 고정할 수 있게 만들었습니다.  
결론적으로는 저는 센서 위치를 완벽하게 맞추는 거는 실패했고, 트랙볼 센서 고정 나사를 대충 조금씩 조이는 방식으로 떼웠습니다.  
제 설정대로 트랙볼을 정상적으로 쓰려면 센서는 반드시 위에 보이는 대로 고정되어야 하며, 이게 엄청 쓰기가 힘들기 때문에 그냥 카리브디스용 보드를 쓰는 걸 강력추천합니다.  

nice!view 오작동  

제가 아는 한 아무도 트랙볼이 달린 ZMK 키보드에 nice!view 를 추가한 적이 없어서, 저는 얘네들의 SPI 장치가 어떻게 상호작용할지, SPI 자체가 뭔지도 몰랐습니다. 
처음에는 얘네 둘이 똑같은 SPI 장치를 쓸 수 있다고 생각해서 똑같은 핀에다 연결했고, 그렇게 연결하니까 nice!view가 위에 보이는 것처럼 오작동했습니다.  
지금 와서 생각하면 이는 매우 멍청한 판단이었으나, 해당 분야에 저는 지식이 없다 보니 제가 얼마나 어리석었는지 알 방법이 없었습니다.  
트랙볼에서 보내는 신호가 전부 nice!view 쪽으로 간섭을 해서 이게 문제가 된 거고, 이제는 얘네가 서로 다른 핀을 써야 한다는 걸 알았습니다.  
저는 트랙볼이 spi1, nice!view는 spi3 를 쓰게 설정했고, 트랙볼과 nice!view를 각각 다른 핀에다 연결하니 그제서야 모든 게 정상작동했습니다.  
이 다음에 혹시 얘네가 똑같은 SPI 장치를 쓸 수 있나 테스트하려고 둘 다 spi1을 쓰게 해봤는데, 이때는 nice!view 화면은 정상적으로 떴지만 트랙볼은 전혀 동작하지 않았습니다.  
어쩌면 제가 뭘 잘못 한 걸 수도 있는데, 적어도 자체 테스트 결과 트랙볼 센서와 nice!view 는 서로 다른 핀과 서로 다른 SPI 장치를 써야 한다고 결론을 내렸습니다.  

## 마무리
이제 키보드는 제대로 작동하게 되었으니, 키스위치랑 키캡을 달기만 하면 제작이 끝나게 됩니다.  
저는 시끄러운 키보드는 싫어서 Gazzew 보바 U4 저소음축을 구했고, 빈티지 가구 느낌을 더 끌어내기 위해 오우거 아연합금 메탈 키캡을 구했습니다.  
메탈 키캡은 처음 몇 분은 차갑게 느껴지나 나중 가면 손가락 온기로 데워지고, 가끔 세게 칠 때 금속음이 나는 게 뭔가 간지가 납니다.  
오우거 메탈키캡은 OEM 프로파일을 지녔고 72개에 6만원 하는데, 수십 만원은 깨질 각오를 해야 하는 알루미늄이나 스테인레스 스틸 키캡보다는 훨씬 저렴합니다.  
허나 아연 키캡은 손가락에 있는 땀하고 기름과 반응해서 변색하기로 유명하니, 어쩌면 몇 달이나 몇 년 후에 교체해야 할 수 있습니다.  
유사 키웰  
얘는 OEM 키캡이라서 1번행은 R4 키캡을 거꾸로, 2번행과 3번행은 각각 R2 와 R3 키캡을 정방향으로 꽂아서 유사 키웰 구조를 만들었습니다.  
어쩌면 다른 키캡을 쓰는 게 나을 수 있었으나, 제가 구할 수 있는 메탈 키캡은 얘 말고 선택지가 없어서 이게 최선이었습니다.  
유사 키웰은 예상과는 다르게 오목한 구조가 매우 쓰기 편했으나 맨 아래행은 오목하지 않고 좀 평평하다는 인상을 받았습니다.
최소한 저에게 있어서 얘는 DSA 키캡과 비교했을 때 나름의 장단점을 가지고 있을 뿐, 꿀리다고 생각하지 않습니다.  
  
의자 마운트  
평소에 저는 맥세이프 어댑터와 141cm 카메라 매직암을 써서 키보드를 의자에 연결해서 씁니다.  
이러면 타이핑하기 편하고, 110mah 배터리로 약 5일 정도 쓸 수 있습니다.  
키보드를 안 쓸 때는 의자에서 탈착한 뒤 텐트에다 올려서 전시합니다.  
  
## 한계점
이걸로 키보드는 완성되었으나 추후에 고쳐야 할 결점이 몇 개 존재합니다.  
글루건을 써서 고정한 niceview    
1. nice!view를 비파괴적으로 설치하는 방법이 필요합니다. 저는 그냥 글루건을 써서 고정했는데, 이런 방식으로는 키보드를 일관성있게 제작할 수 없고, 언젠간 nice!view가 망가져서 교체할 때는 매우 골치가 아플 겁니다.  
2. 우측 스플릿을 의자에서 탈착할 때 가끔 키보드가 리셋됩니다. 어딘가에서 전선이 쇼트를 일으켜서 이러는 거 같은데, 제 와이어링이 엉망이라서 현실적으로 이걸 고칠 방법이 없습니다.  
3. ZMK 펌웨어가 구식입니다. 키보드를 켜고 끌 때마다 좌측 슬레이브가 우측 마스터와 연결하지 못하는데, 이거는 당장 CONFIG_ZMK_BLE_EXPERIMENTAL_CONN=y 를 charybdis.conf 파일에 추가하는 걸로 해결했습니다. 그러나 부작용으로 좌측 스플릿 건전지도 우측만큼 빨리 닳아서 원래 사용시간인 한 달만큼 쓰지 못하고 5일만에 거의 방전이 됩니다. 이건 최신 ZMK 포인터 브랜치 펌웨어를 쓰는 걸로 상대적으로 쉽게 해결할 수 있습니다.  
4. 3x5 카리브디스 나노 펌웨어가 아니라 3x6 카리브디스 미니 펌웨어를 쓰고 있습니다. 비록 기능상 문제는 없긴 하지만 키맵이 3x6 배열이라서 안 쓰는 최외곽열이 계속 있는 게 헷갈립니다. 이는 펌웨어에서 3x5 배열이라고 애초부터 설정하는 게 더 낫습니다.  
5. 트랙볼 센서는 완벽하게 정렬되지 못했습니다. 이게 VOID 의 pmw-3610 어댑터를 써서 ufan의 보드를 고정하는 방식이다 보니, 언제나 똑같은 위치와 높이에 고정되는 카리브디스용 pmw-3610 보드에 비해 위치가 덜 정확합니다. 이렇다 보니 가끔 트랙볼이 작동하지 않을 때가 있는데, 그럴 때마다 트랙볼 센서 고정부 바닥을 꾸욱 누르고 트랙볼을 몇 번 두들겨야 다시 작동합니다. 이를 고치려면 VOID의 pmw-3610 어댑터랑 트랙볼 센서 바닥 모델링을 더 개조해야 하는데, 지금 그걸 하고 있긴 한데 제대로 결과가 나올 때까지는 시행착오를 엄청 겪어야 합니다.  

위에 나열된 한계점을 이유로 저는 이 키보드를 제가 제작한 방식대로 만드는 것을 추천하지 않습니다.  
대신에 플렉서블 PCB, 카리브디스용 pmw-3610 보드, [VOID가 만든 nice!nano 홀더를](https://github.com/victorlucachi/Elite-C-holder)를 쓰고, nice!view 는 일단 안 쓰는 걸 권고합니다.  
한 번에 필요한 재료를 사는 데 있어서 [BastardKB에서 파는 카리브디스 키트를](https://bastardkb.com/charybdis) 구매하는 것도 좋습니다.  
아마 미래에는 3D 모델링 파일을 업데이트할 수도 있는데, 일단은 지금 쓰는 거에 만족해서 이걸 개선하기 위해서는 저한테 매우 큰 동기와 학습이 필요할 겁니다.
